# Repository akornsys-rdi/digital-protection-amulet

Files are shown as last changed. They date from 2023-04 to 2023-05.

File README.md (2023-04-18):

# Skeleton

Akornsys RDI
OSHW SPFMDBC

         ___ _       _     _            
        / __| |_____| |___| |_ ___ _ _  
        \__ \ / / -_) / -_)  _/ _ \ ' \ 
        |___/_\_\___|_\___|\__\___/_||_|

## A repository template

Long description goes here.

## :open_file_folder: Repository content

Skeleton can be obtained on GitHub: [Skeleton](https://github.com/akornsys-rdi/skeleton "Skeleton").

This project may contain some of the following sections:

### Hardware

- `/3d/` 3D modeling, source and rendering designs.
- `/brd/` EDA designs, schematics, PCBs, libraries, datasheets and manufacturing files such as gerber, BoM and PDF.
- `/hdl/` Hardware description files, such as VHDL.

### Software

- `/src/` Firmware or software files, source and compiled.

### Documentation

- `/doc/` Written or graphic documentation.
- Any file containing project information at the root of the project, including the README.
- Wiki or gh-pages if available.

## :rocket: Getting started

Main section. write here all the necessary content for the correct manufacture and assembly. Include all necessary subsections.

Visit the [official documentation](https://readthedocs.org/) to find out a detailed guide.

### 3D Printing

Here can be an optional section of the 3D printing.

### Electronic designs

Here can be an optional section of the electronic design.

### Firmware

Here can be an optional section of the firmware.

### Assembly

Here can be an optional section of the assembly.

## :book: Version history

Skeleton uses [Semantic Versioning](http://semver.org/ "Semantic Versioning"). For the versions available, see the [tags on this repository](https://github.com/akornsys-rdi/skeleton/releases).

Skeleton version [1.0-rc1](#) is the latest stable version.

### Roadmap

Here can be an optional section of the roadmap or ToDo.

## :heart: Community and contributions

Donate using Liberapay (https://liberapay.com/RileyStarlight/donate)
Support me on Ko-Fi (https://ko-fi.com/rileystarlight)
Tindie Shop (https://www.tindie.com)

Contributions are always welcome!

This is a **community-driven open source project**. Any contribution is highly appreciated, whether you are helping [fixing bugs or proposing new features](https://github.com/akornsys-rdi/skeleton/issues "Issues"), [pulling requests](https://github.com/akornsys-rdi/skeleton/pulls "Pull Requests"), improving the documentation or spreading the word.

Please :star: or watch this repository if this project helped you! You can also support this project on [Liberapay](https://liberapay.com/RileyStarlight/donate), [Ko-Fi](https://ko-fi.com/rileystarlight) or buy it in [Tindie](https://www.tindie.com "Tindie Shop").

:warning: **NOTE:** If you are going to make your own copy (clone) or fork, please remove the brand name and logo from your design, as well the S/N. The license and copyright notice must be retained.

## :scroll: Copyright & License

Copyright © 2020 RileyStarlight

### Hardware

Cern OHL-S 2 (https://cern.ch/cern-ohl)

The hardware of this project is licensed under CERN-OHL-S 2, see the [`LICENSE.OHLS2.txt`](LICENSE.OHLS2.txt) file for details.

### Software

GNU/GPL 3 (https://www.gnu.org/licenses/gpl.html "GNU General Public License")

The software of this project is licensed under GNU/GPL 3, see the [`LICENSE.GPL3.txt`](LICENSE.GPL3.txt) file for details.

### Documentation

CC BY SA 4.0 (https://creativecommons.org/licenses/by-sa/4.0/ "Creative Commons BY-SA 4.0")

The documentation of this project is licensed under CC BY SA 4, see the [`LICENSE.BYSA4.txt`](LICENSE.BYSA4.txt) file for details.

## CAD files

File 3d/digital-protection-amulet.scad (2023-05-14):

$fn=36;

translate([1.25,0,-2]) pcb();
difference() {
    union() {
        superior();
        inferior();
    }
    *union() {
        translate([-2,-5,-5]) cube([80,20,20]);
        translate([14,-5,-5]) cube([80,40,20]);
    }
}

module superior() {
    difference() {
        union() {
            hull() {
                translate([0,2.5,0]) rotate([0,90,0]) cylinder(r=5, h=1);
                translate([0,17.5,0]) rotate([0,90,0]) cylinder(r=5, h=1);
                translate([55,2.5,0]) sphere(r=5);
                translate([55,17.5,0]) sphere(r=5);
            }
            translate([60,10,0]) rotate([0,0,-90]) scale([2,1,1.5]) rotate_extrude(convexity = 10) translate([2.5, 0, 0]) circle(r = 0.75);
        }
        union() {
            //silueta
            translate([-1,-3.5,4]) cube([60,27,2]);
            difference() {
                translate([-1,-3.5,-6]) cube([65,27,6]);
                union() {
                    translate([10,-0,-0.2]) cube([1,1,3]);
                    translate([10,19,-0.2]) cube([1,1,3]);
                }
            }
            //interior
            difference() {
                hull() {
                    translate([1,2.5,0]) rotate([0,90,0]) cylinder(r=4, h=1);
                    translate([1,17.5,0]) rotate([0,90,0]) cylinder(r=4, h=1);
                    translate([55,2.5,0]) sphere(r=4);
                    translate([55,17.5,0]) sphere(r=4);
                }
                translate([-1,-3.5,3]) cube([60,27,2]);
                //sujecion pcb
                union() {
                    translate([10,-2.25,-1]) cube([1,3,4]);
                    translate([10,19.25,-1]) cube([1,3,4]);
                    difference() {
                        union () {
                            translate([52.25,10,0]) cylinder(r=2.25,h=5);
                            translate([52.25,10,2]) cylinder(r1=2.25,r2=2.75,h=1);
                        }
                        union() {
                            translate([52.25,10,-1]) cylinder(r=1.2,h=5);
                        }
                    }
                }
                //pestañas
                translate([1,1.2,1.8]) hull() {
                    cube([1,2.6,0.3]);
                    translate([0,0,-0.8]) cube([0.1,2.6,0.1]);
                }
                translate([1,16.2,1.8]) hull() {
                    cube([1,2.6,0.3]);
                    translate([0,0,-0.8]) cube([0.1,2.6,0.1]);
                }
            }
            //borde cierre
            difference() {
                hull() {
                    translate([0.4,-2.5+0.4,-1]) cube([1,24.2,2]);
                    translate([55,2.5,-1]) cylinder(r=4.6, h=2);
                    translate([55,17.5,-1]) cylinder(r=4.6, h=2);
                }
                hull() {
                    translate([2,0,-1]) cube([1,20,2]);
                    translate([55,2.5,-1]) cylinder(r=2.5, h=2);
                    translate([55,17.5,-1]) cylinder(r=2.5, h=2);
                }
            }
            //decoracion
            translate([0,-2.5,3.8]) linear_extrude(1) import("superior.svg");
            translate([0.2,5,-3]) rotate([90,0,-90]) linear_extrude(1) import("duck.svg");
            //tornillo
            translate([52.25,10,0]) cylinder(r=1.2,h=5);
            translate([52.25,10,1.7]) cylinder(r1=1.2,r2=2,h=1.8);
            translate([52.25,10,3.45]) cylinder(r=2,h=2);
            //usb
            translate([-0.5,6.1-0.25,-0.55-0.25]) cube([2,8.5,3.5]);
            //led
            translate([35.814+1.25,20-9.906,0]) cylinder(r=1, h=3.5);
            translate([35.814+1.25,20-9.906,0]) cylinder(r=0.25, h=5);
        }
    }
}

module inferior() {
    difference() {
        union() {
            hull() {
                translate([0,2.5,0]) rotate([0,90,0]) cylinder(r=5, h=1);
                translate([0,17.5,0]) rotate([0,90,0]) cylinder(r=5, h=1);
                translate([55,2.5,0]) sphere(r=5);
                translate([55,17.5,0]) sphere(r=5);
            }
            translate([60,10,0]) rotate([0,0,-90]) scale([2,1,1.5]) rotate_extrude(convexity = 10) translate([2.5, 0, 0]) circle(r = 0.75);
        }
        union() {
            //silueta
            translate([-1,-3.5,-6]) cube([60,27,2]);
            difference() {
                translate([-1,-3.5,0.8]) cube([65,27,6]);
                //pestañas
                union() {
                    translate([1.1,0,0]) cube([2,5,2.75]);
                    translate([1.1,15,0]) cube([2,5,2.75]);
                }
            }
            //interior
            difference() {
                hull() {
                    translate([1,2.5,0]) rotate([0,90,0]) cylinder(r=4, h=1);
                    translate([1,17.5,0]) rotate([0,90,0]) cylinder(r=4, h=1);
                    translate([55,2.5,0]) sphere(r=4);
                    translate([55,17.5,0]) sphere(r=4);
                }
                translate([-2,-3.5,-5]) cube([62,27,2]);
                //sujeccion pcb
                union() {
                    for(i=[5:10:45]) {
                        translate([i,-2.25,-3]) difference() {
                            cube([1,5,2]);
                            translate([-0.5,2,1]) cube([2,4,2]);
                        }
                        translate([i,17.25,-3]) difference() {
                            cube([1,5,2]);
                            translate([-0.5,-1,1]) cube([2,4,2]);
                        }
                        translate([i,8.5,-3]) cube([1,3,1]);
                    }
                    for(i=[6:7:15]) {
                        translate([53.5,i,-3]) difference() {
                            cube([6,1,2]);
                            translate([-1,-0.5,1]) cube([4,2,2]);
                        }
                    }
                    difference() {
                        translate([56.25,0,-3]) cylinder(r=2.75,h=3);
                        union() {
                            translate([56.25,0,-4]) cylinder(r=2.25,h=5);
                        }
                    }
                    difference() {
                        translate([56.25,20,-3]) cylinder(r=2.75,h=3);
                        union() {
                            translate([56.25,20,-4]) cylinder(r=2.25,h=5);
                        }
                    }
                    difference() {
                        union () {
                            translate([52.25,10,-3]) cylinder(r=2.5,h=1);
                            translate([52.25,10,-3]) cylinder(r=1.5,h=2.8);
                        }
                        union() {
                            translate([52.25,10,-4]) cylinder(r=0.75,h=5);
                        }
                    }
                }
                //pestañas
                difference() {
                    union() {
                        translate([1,0,0]) cube([1,5,2.75]);
                        for(i=[ 0,4,15,19 ]) {
                            translate([0,i,0]) hull() {
                                translate([1,0,0]) cube([1,1,2.75]);
                                translate([1,0.3,1]) cube([1.5,0.4,1.75]);
                            }
                        }
                        translate([1,0,0]) hull() {
                            cube([1,5,1]);
                            translate([0,-0.8,0]) cube([0.1,6.6,1]);
                        }
                        translate([1,-1,0]) hull() {
                            cube([1,1,1]);
                            translate([0,-0.5,0]) cube([3,0.1,1]);
                        }
                        translate([1,15,0]) cube([1,5,2.75]);
                        translate([1,15,0]) hull() {
                            cube([1,5,1]);
                            translate([0,-0.8,0]) cube([0.1,6.6,1]);
                        }
                        translate([1,20,0]) hull() {
                            cube([1,1,1]);
                            translate([0,1.5,0]) cube([3,0.1,1]);
                        }
                    }
                    union() {
                        translate([0,-1,0.8]) cube([1.25,7,2.75]);
                        translate([0,1,1]) cube([3,3,1.25]);
                        translate([0,14,0.8]) cube([1.25,7,2.75]);
                        translate([0,16,1]) cube([3,3,1.25]);
                    }
                }
            }
            //borde cierre
            difference() {
                hull() {
                    translate([-1,-2.5,0]) cube([1,25,2]);
                    translate([58,2.5,0]) cylinder(r=5.5, h=2);
                    translate([58,17.5,0]) cylinder(r=5.5, h=2);
                }
                hull() {
                    translate([0.6,-1.8,-1]) cube([1,23.6,4]);
                    translate([55,2.5,-1]) cylinder(r=4.4, h=4);
                    translate([55,17.5,-1]) cylinder(r=4.4, h=4);
                }
            }
            //decoracion
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

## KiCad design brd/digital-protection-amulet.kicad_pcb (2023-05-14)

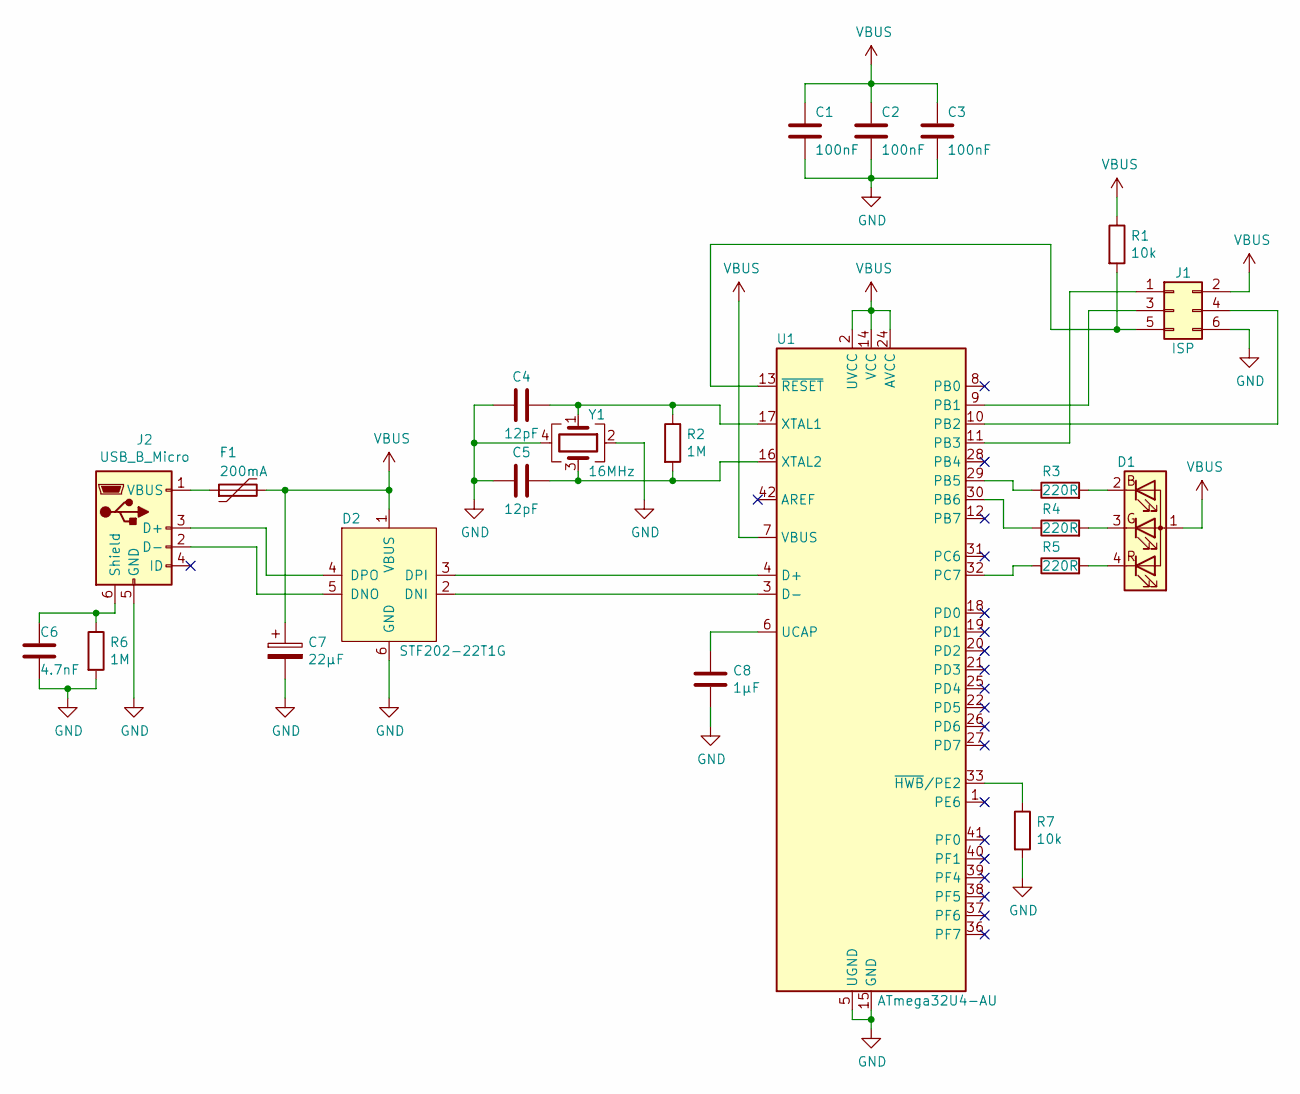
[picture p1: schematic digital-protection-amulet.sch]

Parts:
C1, C2, C3: 100nF; C_0805_2012Metric; Manufacturer Part Number C0805C104M5RACTU
C4, C5: 12pF; C_0805_2012Metric; Manufacturer Part Number CC0805JRNPO9BN120
C6: 4.7nF; C_0805_2012Metric; Manufacturer Part Number C0805C472K5RACTU
C7: 22µF; CP_EIA-3216-18_Kemet-A; Manufacturer Part Number TAJA226M010RNJ
C8: 1µF; C_0805_2012Metric; Manufacturer Part Number CL21B105KOFNNNG
D1: CLMVC-FKC; LED_Cree-PLCC4_2x2mm_CW; Manufacturer Part Number CLMVC-FKC-CGJJM569aBB7a343
D2: STF202-22T1G; TSOP-6_1.65x3.05mm_P0.95mm; Manufacturer Part Number STF202-22T1G
F1: 200mA; Fuse_1210_3225Metric_Castellated; Manufacturer Part Number 0ZCH0020FF2E
J1: ISP; IDC-Header_2x03_P2.54mm_Vertical
J2: USB_B_Micro; USB_Micro-B_Amphenol_10118194_Horizontal; Manufacturer Part Number 10118194-0001LF
R1, R7: 10k; R_0805_2012Metric; Manufacturer Part Number CR0805-JW-103ELF
R2, R6: 1M; R_0805_2012Metric; Manufacturer Part Number CR0805-JW-105ELF
R3, R4, R5: 220R; R_0805_2012Metric; Manufacturer Part Number CR0805-JW-221ELF
U1: ATmega32U4-AU; TQFP-44_10x10mm_P0.8mm; Manufacturer Part Number ATMEGA32U4-AU
Y1: 16MHz; Crystal_SMD_EuroQuartz_X22-4Pin_2.5x2.0mm; Manufacturer Part Number ECS-160-8-36CKM-TR3

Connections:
GND: C1.2, C2.2, C3.2, C4.2, C5.2, C6.2, C7.2, C8.2, D2.6 (GND), J1.6, J2.5 (GND), R6.2, R7.2, U1.5 (UGND), U1.15 (GND), U1.23 (GND), U1.35 (GND), U1.43 (GND), Y1.2, Y1.4
unnamed: C4.1, R2.1, U1.17 (XTAL1), Y1.1
unnamed: C5.1, R2.2, U1.16 (XTAL2), Y1.3
unnamed: C6.1, J2.6 (Shield), R6.1
unnamed: C8.1, U1.6 (UCAP)
unnamed: D1.2 (BK), R3.2
unnamed: D1.3 (GK), R4.2
unnamed: D1.4 (RK), R5.2
unnamed: D2.2 (DNI), U1.3 (D-)
unnamed: D2.3 (DPI), U1.4 (D+)
unnamed: D2.4 (DPO), J2.3 (D+)
unnamed: D2.5 (DNO), J2.2 (D-)
unnamed: F1.1, J2.1 (VBUS)
unnamed: J1.1, U1.11 (PB3)
unnamed: J1.3, U1.9 (PB1)
unnamed: J1.4, U1.10 (PB2)
unnamed: J1.5, R1.2, U1.13 (~RESET)
unnamed: R3.1, U1.29 (PB5)
unnamed: R4.1, U1.30 (PB6)
unnamed: R5.1, U1.32 (PC7)
unnamed: R7.1, U1.33 (~HWB~/PE2)
VBUS: C1.1, C2.1, C3.1, C7.1, D1.1 (A), D2.1 (VBUS), F1.2, J1.2, R1.1, U1.2 (UVCC), U1.7 (VBUS), U1.14 (VCC), U1.24 (AVCC), U1.34 (VCC), U1.44 (AVCC)

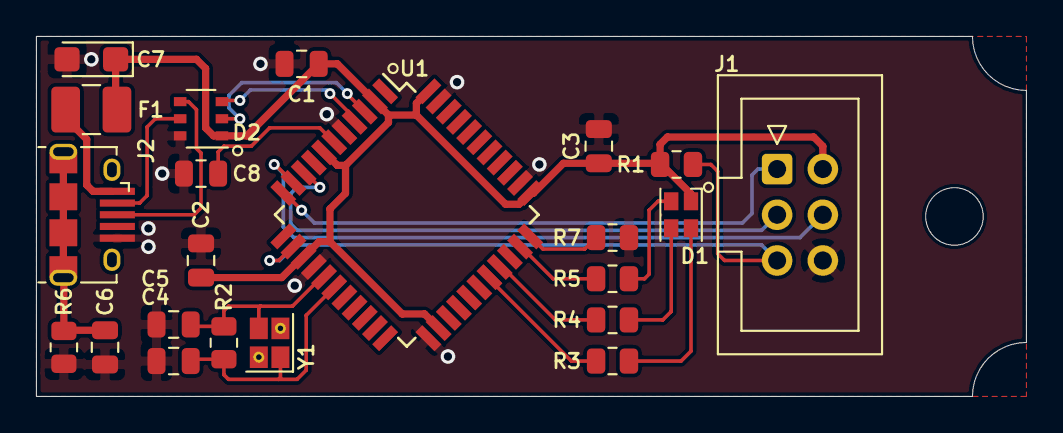
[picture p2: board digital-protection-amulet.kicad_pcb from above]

Board: 2 copper layers, 55.0 x 20.0 mm, 22 parts (0 on the bottom side), 22 nets.

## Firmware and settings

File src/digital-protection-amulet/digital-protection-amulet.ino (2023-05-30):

// `avrdude -patmega32u4 -catmelice_isp -Pusb -Ulfuse:w:0xFF:m -Uhfuse:w:0xD0:m -Uefuse:w:0xCB:m -Ulock:w:0xFF:m`
// `avrdude -patmega32u4 -catmelice_isp -Pusb -Uflash:w:/home/rileystarlight/bin/opt/arduino-1.8.19/hardware/arduino/avr/bootloaders/caterina/Caterina-Micro.hex:i` 

#include <EEPROM.h>

/*  I / O  */
#define RED 13
#define GREEN 10
#define BLUE 9

/*  E E P R O M  */
// HEADER 16 BYTES (2 BYTES LIBRES)
#define EE_MAGIC_NUMBER 0x00   //8 bytes
#define EE_FS_VERSION 0x08     //2 bytes
#define EE_FS_SIZE 0x0A        //4 bytes

// DEVICE CONFIG 32 BYTES (4 BYTES LIBRES)
#define EE_PAGE_COUNT 0x10     //2 bytes
#define EE_BAUDRATE 0x12       //1 bytes
#define EE_CONFIG1 0x13        //1 bytes (aes128) bit7: CRYPTO; bit6: INVALIDATE; bit5: RESTORE; bit4: LOCKED
#define EE_ID 0x18             //8 bytes
#define EE_PASS 0x20           //16 bytes (sha256 & 0xFFFF0000)
#define EE_VERSION 0x30        //4 bytes
#define EE_EDITION 0x34        //1 bytes
#define EE_COLOR_PROFILE 0x35  //1 bytes
#define EE_PIN 0x36            //2 bytes BCD 16-bits pearson hash
#define EE_GROUP 0x38          //8 bytes
#define EE_NAME 0x40           //32 bytes

// SPELL PAGE 928 BYTES (10 BYTES LIBRE)
#define EE_SPELL 0x60          //864 bytes     Spell msg (US after title, title first)
#define EE_META_HASH 0x3C0     //32 bytes      Spell hash (sha256)
#define EE_META_LENGTH 0x3E0   //2 bytes       Spell msg size
#define EE_META_REV 0x3E2      //2 bytes       Spell revision
#define EE_META_EPOCH 0x3E4    //8 bytes       Spell epoch (64-bit unix epoch)
#define EE_META_I18N 0x3EC     //3 bytes       Spell lang (ISO 639‑3) "spa"
#define EE_META_CHSUM 0x3EF    //1 bytes       Spell chsum (sum8)
#define EE_META_TIMES 0x3FA    //2 bytes       Page times written
#define EE_META_LINKFWD 0x3FC  //2 bytes       Next page
#define EE_META_LINKBWD 0x3FE  //2 bytes       Previous page

/*  C O N S T A N T S  */
#define MAGIC_NUMBER_LENGTH 8
#define MAGIC_NUMBER "\x7D\x73\xA4\x1C\xDC\x7E\xFA\xCD"
#define MAX_FS_VERSION 1

/*  E N U M  */
enum ee_status_t {
    UNINITIALIZED = -1,
    UNKNOWN = 0,
    INITIALIZED = 1,
    VALID = 2
};

enum baudrate_t {
    BR1200 = 1,
    BR4800 = 2,
    BR9600 = 3,
    BR19200 = 4,
    BR38400 = 5,
    BR57600 = 6,
    BR115200 = 7
};

void setup() {
    pinMode(RED, OUTPUT);
    pinMode(GREEN, OUTPUT);
    pinMode(BLUE, OUTPUT);
    digitalWrite(RED, HIGH);
    digitalWrite(GREEN, HIGH);
    digitalWrite(BLUE, HIGH);
    SerialUSB.begin(9600);
    for (unsigned char i = 255; i > 1; i--) {
        analogWrite(RED, i);
        delay(1);
    }
    for (unsigned char i = 255; i > 1; i--) {
        analogWrite(GREEN, i);
        delay(1);
    }
    for (unsigned char i = 0; i < 255; i++) {
        analogWrite(RED, i);
        delay(1);
    }
    for (unsigned char i = 255; i > 1; i--) {
        analogWrite(BLUE, i);
        delay(1);
    }
    for (unsigned char i = 0; i < 255; i++) {
        analogWrite(GREEN, i);
        delay(1);
    }
    for (unsigned char i = 255; i > 1; i--) {
        analogWrite(RED, i);
        delay(1);
    }
    for (unsigned char i = 0; i < 255; i++) {
        analogWrite(BLUE, i);
        analogWrite(RED, i);
        delay(1);
    }
}

void loop() {
    static bool first_run = true;
    static bool connected = false;
    static bool printed = false;
    static bool empty = true;
    static char dir = -1;
    unsigned char c = '\0';
    static unsigned char v = 255;
    static unsigned int length = 0;
    static unsigned long t = 0;
    static unsigned long t_led = 0;

    if (first_run) {
        if (EEPROM.read(EE_PAGE_COUNT + 1)) empty = false;
        length = (EEPROM.read(EE_META_LENGTH) << 8);
        length |= (EEPROM.read(EE_META_LENGTH + 1));
        first_run = false;
    }
    if ((millis() - t >= 100) && (!connected)) {
        t = millis();
        connected = SerialUSB;
    }
    if (empty) {
        if ((connected) && (!printed)) {
            SerialUSB.println("Digital Protection Amulet");
            SerialUSB.println("Special Edition: Unique version for Patri");
            SerialUSB.println("\nNo spells found.");
            printed = true;
        }
        digitalWrite(RED, (millis() & 0x80));
    }
    else {
        if ((connected) && (!printed)) {
            SerialUSB.println("Digital Protection Amulet");
            SerialUSB.println("Special Edition: Unique version for Patri");
            SerialUSB.println("\nOne spell found.");
            SerialUSB.print("\nSpell title: ");
            for (unsigned int i = 0; i < length; i++) {
                c = EEPROM.read(EE_SPELL + i);
                if (c == 0x1F) SerialUSB.print("\n\n    \"");
                else if (c == 0x0A) SerialUSB.print("\n    ");
                else if (c != 0x00) SerialUSB.print(char(c));
            }
            SerialUSB.println("\"\n");
            SerialUSB.println("No other spells found.");
            printed = true;
        }
        if (millis() - t_led >= 3) {
            t_led = millis();
            v += dir;
            if ((v == 255) || (v == 0)) dir = -dir;
            analogWrite(RED, v);
            analogWrite(BLUE, v);
        }
    }
}

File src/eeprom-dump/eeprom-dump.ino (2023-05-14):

#include <EEPROM.h>

/*  E E P R O M  */
// HEADER 16 BYTES (2 BYTES LIBRES)
#define EE_MAGIC_NUMBER 0x00   //8 bytes
#define EE_FS_VERSION 0x08     //2 bytes
#define EE_FS_SIZE 0x0A        //4 bytes

// CONFIG 32 BYTES (12 BYTES LIBRES)
#define EE_PAGE_COUNT 0x10     //2 bytes
#define EE_BAUDRATE 0x12       //1 bytes
#define EE_CONFIG1 0x13        //1 bytes (aes128) bit0: CRYPTO
#define EE_PASS 0x20           //16 bytes (sha256 & 0xFFFF0000)

// DEVICE 48 BYTES (3 BYTES LIBRES)
#define EE_VERSION 0x30        //4 bytes
#define EE_EDITION 0x34        //1 bytes
#define EE_ID 0x38             //8 bytes
#define EE_MODEL 0x40          //32 bytes

// SPELL PAGE 928 BYTES (14 BYTES LIBRE)
#define EE_SPELL 0x60          //864 bytes     Spell msg (US after title, title first)
#define EE_META_HASH 0x3C0     //32 bytes      Spell hash (sha256)
#define EE_META_LENGTH 0x3E0   //2 bytes       Spell msg size
#define EE_META_REV 0x3E2      //2 bytes       Spell revision
#define EE_META_EPOCH 0x3E4    //4 bytes       Spell epoch
#define EE_META_I18N 0x3E8     //3 bytes       Spell lang (ISO 639‑3) "spa"
#define EE_META_CHSUM 0x3EB    //1 bytes       Spell chsum (sum)
#define EE_META_TIMES 0x3FA    //2 bytes       Page times written
#define EE_META_LINKFWD 0x3FC  //2 bytes       Next page
#define EE_META_LINKBWD 0x3FE  //2 bytes       Previous page


void setup() {
    SerialUSB.begin(9600);
    while(!SerialUSB);
}

void loop() {
    unsigned char c = 0;
    SerialUSB.println("EEPROM DUMP\n");
    for(unsigned int i = 0; i < EEPROM.length(); i++) {
        SerialUSB.print("0x");
        SerialUSB.print(i, HEX);
        SerialUSB.print(" - 0x");
        SerialUSB.println(EEPROM.read(i),HEX);
    }

    SerialUSB.print("\nMAGIC NUMBER - 0x");
    for(unsigned int i = EE_MAGIC_NUMBER; i < EE_MAGIC_NUMBER + 8; i++) {
        SerialUSB.print(EEPROM.read(i), HEX);
    }

    SerialUSB.print("\nFS VERSION - 0x");
    for(unsigned int i = EE_FS_VERSION; i < EE_FS_VERSION + 2; i++) {
        SerialUSB.print(EEPROM.read(i), HEX);
    }

    SerialUSB.print("\nFS SIZE - 0x");
    for(unsigned int i = EE_FS_SIZE; i < EE_FS_SIZE + 4; i++) {
        SerialUSB.print(EEPROM.read(i), HEX);
    }

    SerialUSB.print("\nFCONFIG EMPTY - 0x");
    for(unsigned int i = EE_PAGE_COUNT; i < EE_PAGE_COUNT + 2; i++) {
        SerialUSB.print(EEPROM.read(i), HEX);
    }

    SerialUSB.print("\nCONFIG BAUDRATE - 0x");
    SerialUSB.print(EEPROM.read(EE_BAUDRATE), HEX);

    SerialUSB.print("\nCONFIG CONFIG - 0x");
    SerialUSB.print(EEPROM.read(EE_CONFIG1), HEX);

    SerialUSB.print("\nCONFIG PASS - 0x");
    for(unsigned int i = EE_PASS; i < EE_PASS + 16; i++) {
        SerialUSB.print(EEPROM.read(i), HEX);
    }

    SerialUSB.print("\nDEVICE VERSION - 0x");
    for(unsigned int i = EE_VERSION; i < EE_VERSION + 4; i++) {
        SerialUSB.print(EEPROM.read(i), HEX);
    }

    SerialUSB.print("\nDEVICE EDITION - 0x");
    SerialUSB.print(EEPROM.read(EE_EDITION), HEX);

    SerialUSB.print("\nDEVICE ID - 0x");
    for(unsigned int i = EE_ID; i < EE_ID + 8; i++) {
        SerialUSB.print(EEPROM.read(i), HEX);
    }

    SerialUSB.print("\nDEVICE MODEL - ");
    for(unsigned int i = EE_MODEL; i < EE_MODEL + 32; i++) {
        SerialUSB.print(char(EEPROM.read(i)));
    }

    SerialUSB.println("\nSPELL [");
    for(unsigned int i = EE_SPELL; i < EE_SPELL + 864; i=i+32) {
        for(unsigned int j = i; j < i + 32; j++) {
            SerialUSB.print(char(EEPROM.read(j)));
        }
        SerialUSB.println();
    }
    SerialUSB.print("]");

    SerialUSB.print("\nSPELL HASH - 0x");
    for(unsigned int i = EE_META_HASH; i < EE_META_HASH + 32; i++) {
        SerialUSB.print(EEPROM.read(i), HEX);
    }

    SerialUSB.print("\nSPELL LENGTH - 0x");
    for(unsigned int i = EE_META_LENGTH; i < EE_META_LENGTH + 2; i++) {
        SerialUSB.print(EEPROM.read(i), HEX);
    }

    SerialUSB.print("\nSPELL REV - 0x");
    for(unsigned int i = EE_META_REV; i < EE_META_REV + 2; i++) {
        SerialUSB.print(EEPROM.read(i), HEX);
    }

    SerialUSB.print("\nSPELL EPOCH - 0x");
    for(unsigned int i = EE_META_EPOCH; i < EE_META_EPOCH + 4; i++) {
        SerialUSB.print(EEPROM.read(i), HEX);
    }

    SerialUSB.print("\nSPELL I18N - ");
    for(unsigned int i = EE_META_I18N; i < EE_META_I18N + 3; i++) {
        SerialUSB.print(char(EEPROM.read(i)));
    }

    SerialUSB.print("\nSPELL CKSUM - 0x");
    SerialUSB.print(EEPROM.read(EE_META_CHSUM), HEX);

    SerialUSB.print("\nPAGE TIMES WRITTEN - 0x");
    for(unsigned int i = EE_META_TIMES; i < EE_META_TIMES + 2; i++) {
        SerialUSB.print(EEPROM.read(i), HEX);
    }

    SerialUSB.print("\nPAGE LINK FORWARD- 0x");
    for(unsigned int i = EE_META_LINKFWD; i < EE_META_LINKFWD + 2; i++) {
        SerialUSB.print(EEPROM.read(i), HEX);
    }

    SerialUSB.print("\nPAGE LINK BACKWARD - 0x");
    for(unsigned int i = EE_META_LINKBWD; i < EE_META_LINKBWD + 2; i++) {
        SerialUSB.print(EEPROM.read(i), HEX);
    }

    while(1);
}

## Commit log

2023-05-14 unique version for Patri
    [digital-protection-amulet.kicad_pcb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]
2023-05-15 cambiado registro epoch para resolver Y2038
    [digital-protection-amulet.ino]

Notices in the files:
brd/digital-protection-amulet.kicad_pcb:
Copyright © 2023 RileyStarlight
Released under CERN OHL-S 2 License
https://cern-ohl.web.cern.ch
